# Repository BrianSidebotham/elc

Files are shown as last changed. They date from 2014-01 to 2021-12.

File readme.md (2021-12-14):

# Electronic Load Controller

This project is subject to the [CERN Open Hardware Licence](http://www.ohwr.org/attachments/2388/cern_ohl_v_1_2.txt)

Electronic Load Controller Design is available [here](http://ludens.cl/Electron/picelc/picelc.html).

This repository is a direct implementation of the ludens.cl ELC circuit.

The Schematic and Printed Circuit Board have been produced in
[KiCad](https://kicad.org). The Printed circuit board has been routed
single-layer so it may be possible to etch your own easily enough. Otherwise it
can be made very cheaply. There's plenty of improvements that can be made to
the design, and there's plenty of optimisations for the PCB layout too if you
fancy changing things up.

To use this Load Controller you'll need a way to program the PIC microcontroller
and you'll have to use the [code available on the lidens.cl website](http://ludens.cl/Electron/picelc/picelc.bas).
Perhaps they can make a binary available for anyone to use without them having
to use the PIC basic compiler.

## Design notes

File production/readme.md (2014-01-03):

ELC
===

This project is subject to the CERN Open Hardware Licence
( http://www.ohwr.org/attachments/2388/cern_ohl_v_1_2.txt )

Electronic Load Controller Design is available at
http://ludens.cl/Electron/picelc/picelc.html

This repository is a direct implementation of the ludens.cl ELC circuit.

The Schematic and Printed Circuit Board have been produced in KiCad
(  http://kicad-pcb.org ). The Printed circuit board has been routed
single-layer so it may be possible to etch your own easily enough. Otherwise it
can be made very cheaply. There's plenty of improvements that can be made to
the design, and there's plenty of optimisations for the PCB layout too if you
fancy changing things up.

To use this Load Controller you'll need a way to program the PIC microcontroller
and you'll have to use the code available of the lidens.cl website:
( http://ludens.cl/Electron/picelc/picelc.bas ). Perhaps they can make a binary
available for anyone to use without them having to use the PIC basic compiler.

Production Files
----------------

Production files are RS247X Gerber files suitable for PCB manufacturing with
an excellon drill tape file. The PCB has been routed single-sided and can be
made from any substrate such as FR-4 or paper-based substrates as desired.

The gerbers include the top and bottom layer, where the top layer only includes
the through-hole pad annulus's.

Production files are not yet released!

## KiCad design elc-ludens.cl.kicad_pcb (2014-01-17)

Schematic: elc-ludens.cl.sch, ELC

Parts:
C1: 220pF; Farnell 9411755
C2: 33uF; Farnell 1902890
C3: 3300uF; Farnell 1902894
C4: 10uF; Farnell 1236657
C5: 0.1uF; Farnell 2309020
C6, C7: 22pF; Farnell 1457695
D1, D2, D5, D6: 1N4004; Farnell 2317685
D3, D4: 1N4148; Farnell 2336736
D7: GREEN; Farnell 2217954
P1, P2, P3: CONN_2; Farnell 1172817
P4: CONN_8; Farnell 1142163
P5, P6, P7: CONN_1
Q1, Q2, Q3, Q4, Q5, Q6, Q7, Q8: BC337; TO92-EBC
R1: 4k7; Farnell 2329534
R2, R3, R4, R5, R6, R11, R12, R13, R14: 2k2; Farnell 2329508
R7, R8, R9, R10, R15, R16, R17, R18: 47R; Farnell 2329533
R19: 330R; Farnell 2329514
R20: 2k2
U1: 7805; Farnell 1564483
U2: PIC16F628; Farnell 9760423
X1: 4MHz; Farnell 1842254

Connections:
/COMP1: C1.1, D3.2 (K), D4.1 (A), R1.2, U2.18 (RA1/AN1)
/COMP2: C1.2, C2.1, D3.1 (A), D4.2 (K), P3.2 (PM), R2.1, R20.2, U2.1 (RA2/AN2/VREF)
/DRV1: R3.1, U2.6 (RB0/INT)
/DRV2: R4.1, U2.7 (RB1/RX/DT)
/DRV3: R5.1, U2.8 (RB2/TX/CK)
/DRV4: R6.1, U2.9 (RB3/CCP1)
/DRV5: R11.1, U2.17 (RA0/AN0)
/DRV6: R12.1, U2.11 (RB5)
/DRV7: R13.1, U2.12 (RB6/T1OSC0/T1CKI/PGC)
/DRV8: R14.1, U2.13 (RB7/T1OSI/PGD)
/GATE1: P4.1, R7.2
/GATE2: P4.2, R8.2
/GATE3: P4.3, R9.2
/GATE4: P4.4, R10.2
/GATE5: P4.5, R15.2
/GATE6: P4.6, R16.2
/GATE7: P4.7, R17.2
/GATE8: P4.8, R18.2
GND: C2.2, C3.2, C4.2, C5.2, C6.2, C7.2, D2.1 (A), D6.1 (A), D7.2 (K), Q1.E, Q2.E, Q3.E, Q4.E, Q5.E, Q6.E, Q7.E, Q8.E, R2.2, U1.GND, U2.5 (VSS), U2.10 (RB4/PGM)
unnamed: Q5.C, R15.1
unnamed: Q6.B, R12.2
unnamed: Q5.B, R11.2
unnamed: Q7.B, R13.2
unnamed: Q7.C, R17.1
unnamed: Q6.C, R16.1
unnamed: Q2.B, R4.2
unnamed: Q2.C, R8.1
unnamed: Q1.C, R7.1
unnamed: Q4.B, R6.2
unnamed: Q4.C, R10.1
unnamed: Q3.B, R5.2
unnamed: Q3.C, R9.1
unnamed: Q1.B, R3.2
unnamed: Q8.C, R18.1
unnamed: Q8.B, R14.2
unnamed: P3.1, R1.1
unnamed: R19.1, U2.2 (RA3/AN3/CMP1)
unnamed: D5.1 (A), D6.2 (K), P2.2 (PM)
unnamed: D1.1 (A), D2.2 (K), P2.1
unnamed: C3.1, D1.2 (K), D5.2 (K), U1.VI
unnamed: C7.1, U2.15 (OSC2), X1.1
unnamed: C6.1, U2.16 (OSC1), X1.2
unnamed: D7.1 (A), R19.2
VDD: C4.1, C5.1, P1.2 (PM), R20.1, U1.VO, U2.4 (MCLR), U2.14 (VDD)

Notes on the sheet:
USE PDIP PACKAGE
MECHANICAL FIXINGS

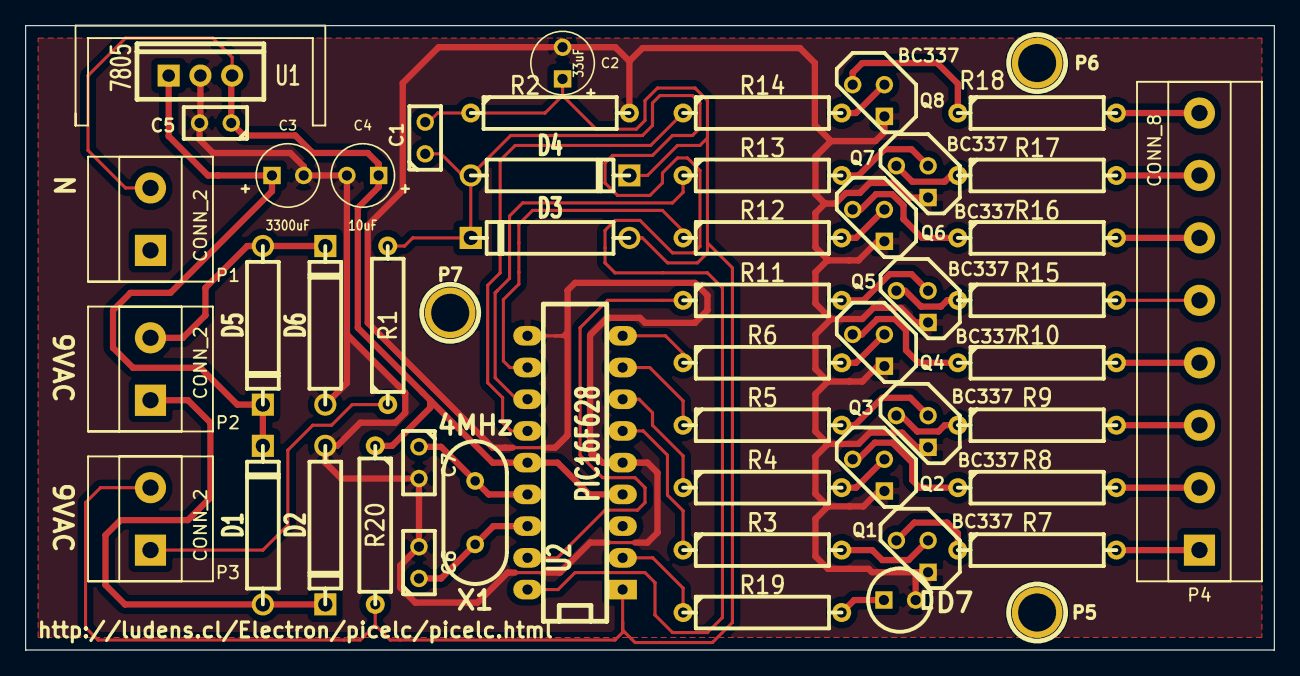
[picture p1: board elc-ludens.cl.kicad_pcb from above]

Board: 2 copper layers, 100.0 x 50.0 mm, 52 parts (0 on the bottom side), 44 nets.

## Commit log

2014-01-03 First revision bought into version control
    Electronic Load Controller Project
    [elc-ludens.cl.kicad_pcb, elc-ludens.cl.sch]
2014-01-03 Tidy PCB and add Fixing Holes
    Must use nylon/plastic hardware to use the fixing holes
    [elc-ludens.cl.kicad_pcb, elc-ludens.cl.sch]
2014-01-06 Add missing resistor
    [elc-ludens.cl.kicad_pcb, elc-ludens.cl.sch]
2014-01-17 Layout fix BC337 pinout + Add resistor
    [elc-ludens.cl.kicad_pcb, elc-ludens.cl.sch]
2014-01-30 Finalise PCB Design and produce production gerbers
    [elc-ludens.cl.sch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]
2021-11-08 Update readme.md
    https://forum.kicad.info/t/warning-avoid-all-links-to-kicad-pcb-org-use-kicad-org/31521
